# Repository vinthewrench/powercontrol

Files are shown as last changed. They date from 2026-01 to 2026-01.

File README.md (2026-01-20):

This repository contains a hardware power controller that enforces safe, predictable power-on and power-off behavior for a Raspberry Pi used in real-world automation systems.

It grew out of the work described in [Raspberry Pi Internet of Things – Part 029](https://www.vinthewrench.com/p/raspberry-pi-internet-of-things-part-029), where the problem wasn’t software, but power: a Pi running irrigation, valves, radios, or sensors cannot simply lose power without consequences. Filesystems corrupt, tasks stop mid-cycle, and batteries get drained dry.

The design documented here takes those ideas further by moving power control out of the Pi and into a small, dedicated controller. The Pi decides when it is safe to shut down; the hardware enforces when power is actually applied or removed. A latching relay does the physical switching, while simple signals coordinate startup, shutdown, and recovery when utility power fails or returns.

The result is a Raspberry Pi that behaves like part of a system, not a hobby board dangling from a power supply.
 
## Repository Layout

```
.
├── Power_Controller_Design_Document_v1.1.md
├── README.md
├── code/
│   └── powercontrol/
│       ├── powercontrol.c
│       ├── makefile
│       └── Doxyfile
└── hw/
    └── powercontrol_2.1/
        ├── powercontrol_2.1.kicad_sch
        ├── powercontrol_2.1.kicad_pcb
        ├── powercontrol_2.1.kicad_pro
        ├── powercontrol_2.1.kicad_prl
        └── build.zip
```

---

## Documentation

### Power_Controller_Design_Document_v1.1.md

This is the **authoritative design specification** for this project.

It defines:
- Hardware intent
- Firmware behavior
- I2C command contract
- Extended readback interface (`0xF0`)
- Design philosophy and explicit non-goals

## Firmware (`code/powercontrol`)

### Overview

The firmware runs on an AVR (ATmega8 / ATmega88 class) and provides:

- Latching relay control (pulse-only, never held)
- Manual wake via INT0
- AC_OK wake via INT1
- Red / Green status LEDs
- I2C slave interface (address `0x08`)
- Watchdog-style host supervision
- Low-power IDLE sleep when inactive

The firmware is **single-loop, flag-driven**, and avoids performing real work in ISRs.

### Files

- `powercontrol.c`  
  Main firmware implementation. This is the source of truth.

- `makefile`  
  Minimal AVR-GCC build file. No build system gymnastics.

- `Doxyfile`  
  Optional Doxygen configuration for generating internal documentation.

### Build

Typical workflow:

```
cd code/powercontrol
make
make flash
```

Target MCU, programmer, and fuses are defined in the makefile and are expected to be adjusted per environment.

## Hardware (`hw/powercontrol_2.1`)

This directory contains the **KiCad revision 2.1** of the Power Controller board.

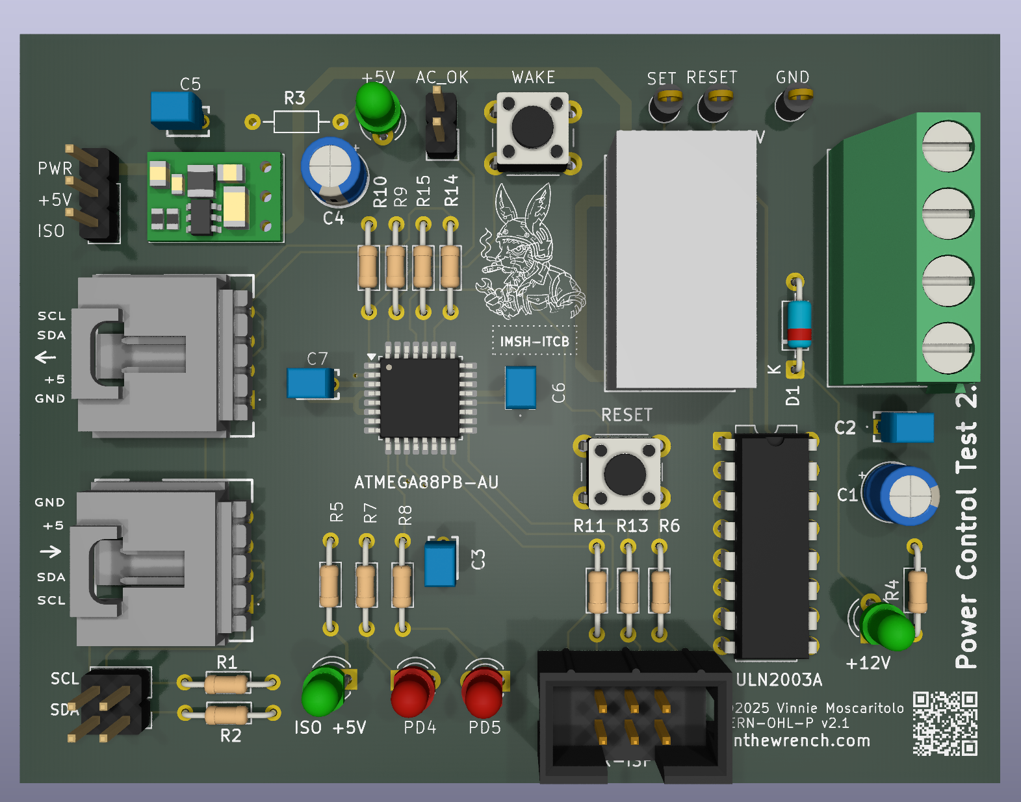
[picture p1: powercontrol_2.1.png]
Power Controller v2.1


### Hardware Summary

- +12 V input
- On-board 5 V regulator
- AVR MCU running internal 8 MHz RC oscillator
- ULN2003A relay driver
- Dual-coil latching relay
- Manual wake button
- AC_OK external wake input
- I2C interface with series protection resistors
- Explicit power and ground wiring (no hidden pins)

The MCU remains powered at all times so it can observe wake events even when the downstream system is off.

### Fabrication

`build.zip` contains fabrication outputs (Gerbers, drill files, etc.) suitable for board manufacturing.

## I2C Interface (Summary)

- **Address**: `0x08`
- **Write-only commands** for relay and LED control
- **Extended readback** via command `0xF0`

Example:

```
i2ctransfer -y 1 w1@0x08 0xF0 r4
```

Expected response:

```
0x13 status_byte timer_MSB timer_LSB
```

###  I2C Command Set

| Command | Function |
|---|---|
| 0x00 | NO-OP watchdog ping |
| 0x01 | Relay OFF |
| 0x02 | Relay ON |
| 0x03 | Red LED OFF |
| 0x04 | Red LED ON |
| 0x05 | Green LED OFF |
| 0x06 | Green LED ON |
| 0x10 | Set ping timeout (uint16 ms) |

---

## Non-Goals

This project explicitly does **not** attempt to provide:

- RTC or scheduling
- Network connectivity
- Filesystems
- Soft power control
- UPS functionality

Those responsibilities belong on the host system.

## Design Intent (Plain English)

If the host behaves, it stays powered.  
If it locks up, it gets cut off and restarted.  
If a human presses the button, power comes on.  
If AC disappears, the system reacts predictably.

## License

- **Firmware / Software**: MIT License  
- **Hardware designs**: CERN-OHL-P v2 (Permissive Open Hardware Licence)

Copyright © 2026 Vinnie Moscaritolo

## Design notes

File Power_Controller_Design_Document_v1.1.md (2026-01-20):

# Power Controller Design Document

## 1. Purpose

The Power Controller is a small, deterministic embedded controller whose sole job is to reliably apply and remove power to a downstream system (typically a Raspberry Pi or similar SBC), while providing:

- Hard power cut and restore via a latching relay
- Manual wake capability
- External wake from an AC-present signal
- Simple visual status via red/green LEDs
- A minimal I2C command interface
- Predictable low-power idle behavior

This board is intentionally boring. No cloud, no OS assumptions, no timing magic. It exists to do one thing well: decide when power flows.

---

## 2. Design Philosophy

- Deterministic: All behavior is explicit and bounded.
- Offline-first: No network dependency.
- Fail-safe bias: Loss of MCU control defaults to relay OFF.
- Serviceable: ISP header, visible LEDs, simple signals.
- Conservative silicon: AVR, ULN2003, latching relay.

---

## 3. Functional Overview

The controller runs continuously from +12 V and selectively switches a separate +12 V switched output feeding the downstream system.

---

## 4. Hardware Architecture

### 4.1 Microcontroller

- ATmega8 / ATmega88 class AVR
- Internal 8 MHz RC oscillator
- No external crystal

### 4.2 Power Regulation

- +12 V input
- Pololu D45V5F5 buck regulator
- +5 V MCU rail

### 4.3 Relay Driver

- Dual-coil latching relay
- ULN2003A driver
- Pulse-only coil drive

### 4.4 LEDs

- Red: fault/timeout
- Green: power ON
- Active-low GPIO drive

### 4.5 Wake Inputs

- INT0: manual wake button
- INT1: AC_OK relay contact

### 4.6 I2C Interface

- Slave address: 0x08
- Watchdog, relay, LED control

---

## 5. Firmware Architecture

- Single main loop
- ISRs set flags only
- IDLE sleep when inactive

### 5.0 Extended I2C Readback

The controller supports an extended read transaction for diagnostics and host verification.

**Command**: `0xF0`  
**Read length**: 4 bytes

**Response format**:

| Byte | Description |
|---|---|
| 0 | Firmware version (`0x13`) |
| 1 | Status byte |
| 2 | Timer MSB |
| 3 | Timer LSB |

**Linux example**:

```
i2ctransfer -y 1 w1@0x08 0xF0 r4
```

**Expected response example**:

```
0x13 0x00 0x00 0x00
```

This indicates firmware version 0x13, status = 0, and timer = 0 ms.

This read path is side-effect free and may be called at any time.

---

### 5.1 I2C Command Set

| Command | Function |
|---|---|
| 0x00 | NO-OP watchdog ping |
| 0x01 | Relay OFF |
| 0x02 | Relay ON |
| 0x03 | Red LED OFF |
| 0x04 | Red LED ON |
| 0x05 | Green LED OFF |
| 0x06 | Green LED ON |
| 0x10 | Set ping timeout (uint16 ms) |

---

## 6. Safety and Robustness

- Series resistors on ISP and I2C
- No +12 V exposure to MCU pins
- Latching relay prevents thrash

---

## 7. Use Cases

- SBC power watchdog
- Unattended systems
- Farm and off-grid electronics

---

## 8. Non-Goals

- No RTC
- No scheduler
- No network stack

---

## 9. Summary

Power should be deliberate, observable, and recoverable.

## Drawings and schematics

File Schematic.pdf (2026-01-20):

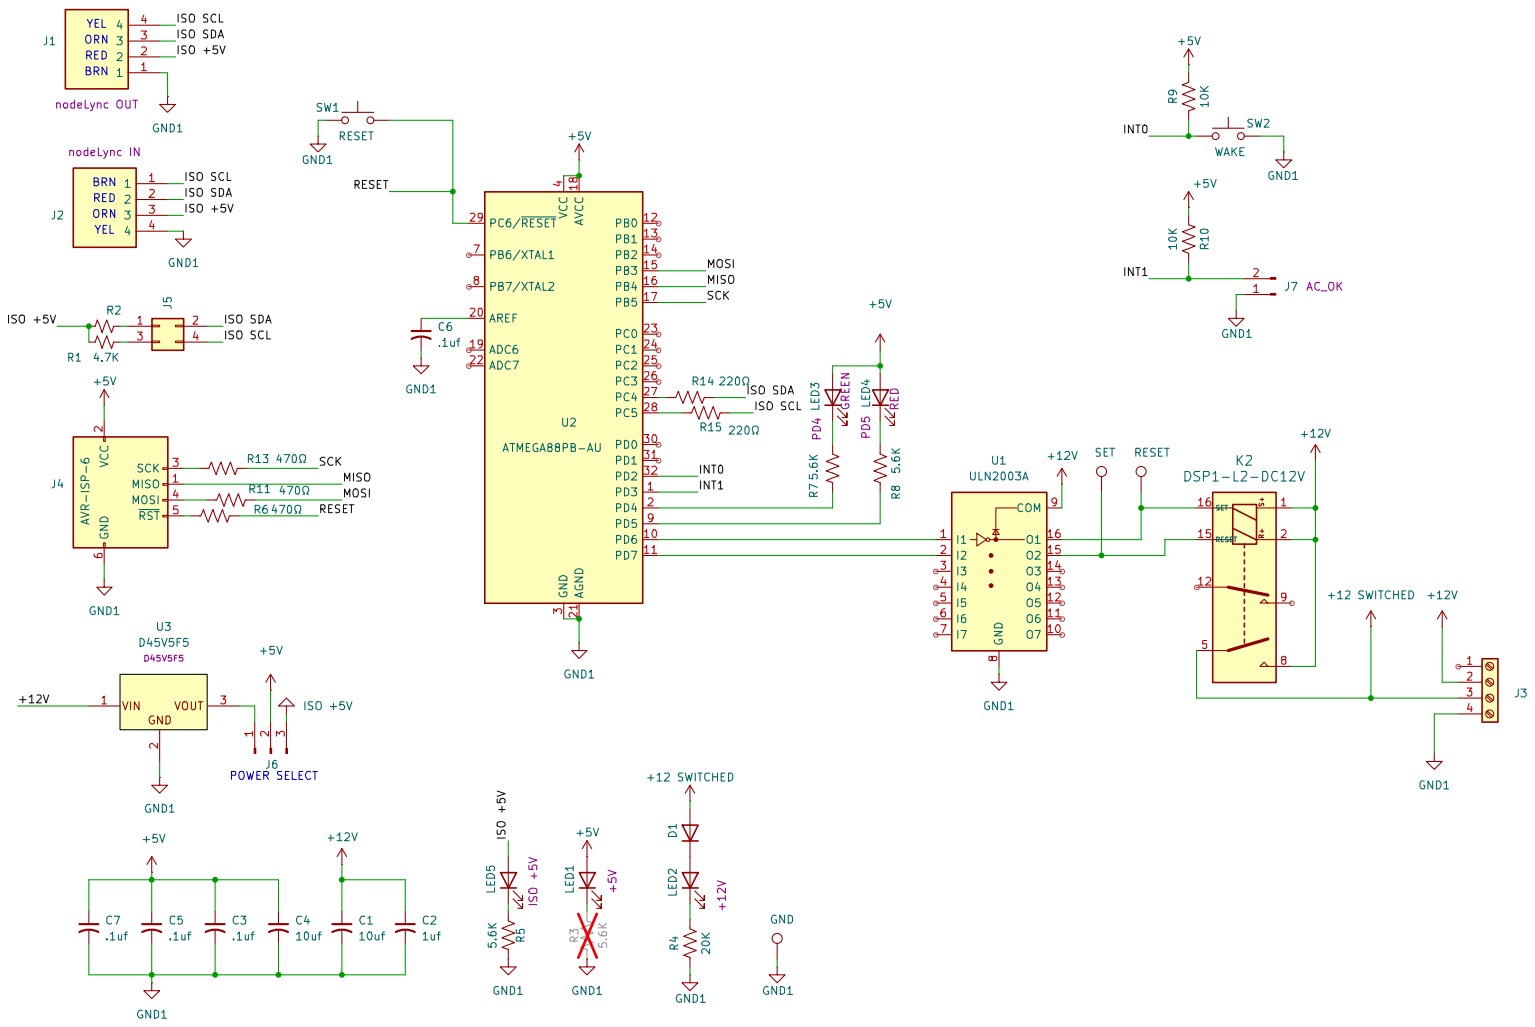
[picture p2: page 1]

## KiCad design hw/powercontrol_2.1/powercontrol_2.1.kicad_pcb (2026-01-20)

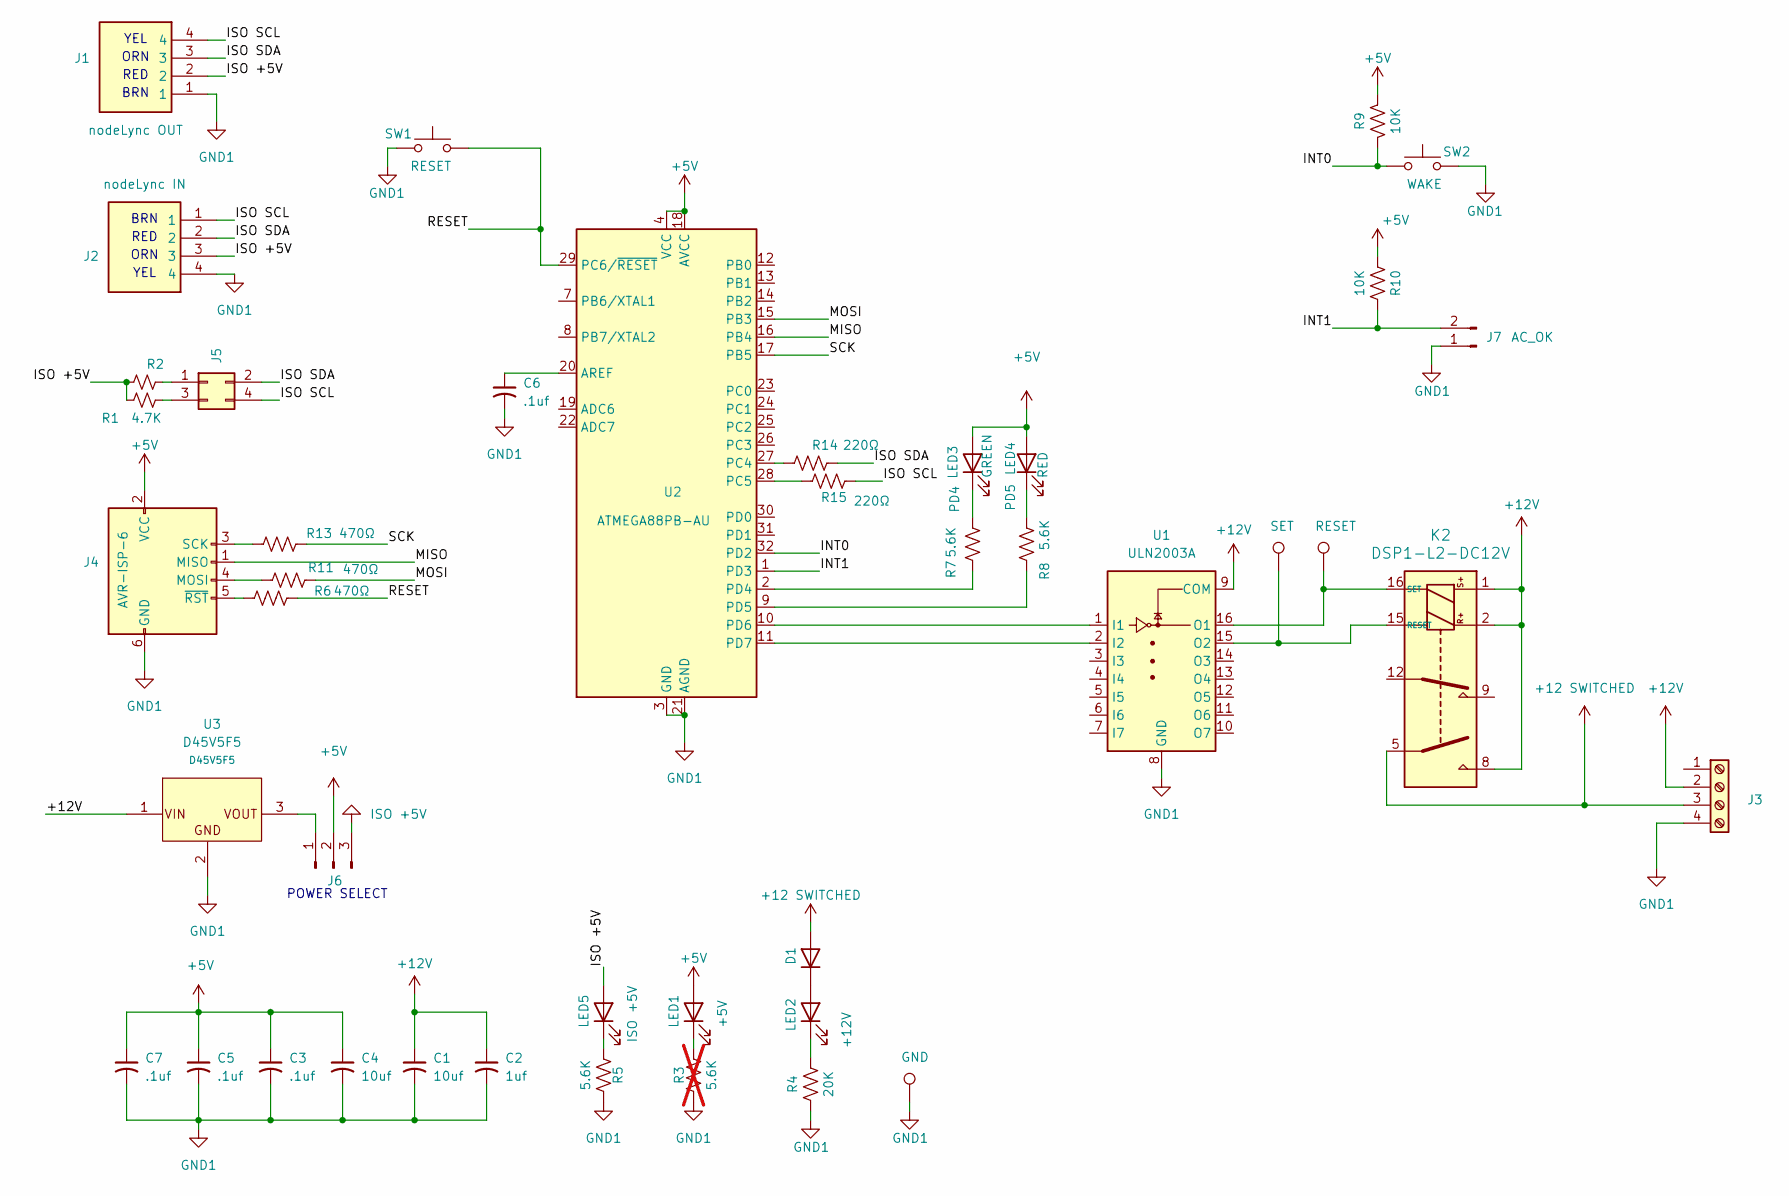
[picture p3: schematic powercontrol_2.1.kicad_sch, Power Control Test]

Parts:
C1, C4: 10uf; CP_Radial_D5.0mm_P2.00mm
C2: 1uf; RCER71H104K0DBH03A
C3, C5, C6, C7: .1uf; RCER71H104K0DBH03A
D1: 1N4148WS; D_DO-35_SOD27_P7.62mm_Horizontal
J1, J2: 70551-0003; 705510003; Manufacturer_Part_Number 70551-0003; Mouser Part Number 538-70551-0003
J3: +12; TerminalBlock_Phoenix_MKDS-1,5-4-5.08_1x04_P5.08mm_Horizont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
J4: AVR-ISP-6; PinHeader_2x03_P2.54mm_Vertical
J5: Conn_02x02_Odd_Even; PinHeader_2x02_P2.54mm_Vertical
J6: Conn_01x03_Pin; PinHeader_1x03_P2.54mm_Vertical
J7: Conn_01x02_Pin; PinHeader_1x02_P2.54mm_Vertical
K2: DSP1-L2-DC12V
LED1, LED2, LED3, LED5: 151033GS03000; LED_D3.0mm
LED4: 151033RS03000; LED_D3.0mm
R1, R2: 4.7K; R_Axial_DIN0204_L3.6mm_D1.6mm_P7.62mm_Horizontal
R3: 5.6K; R_Axial_DIN0204_L3.6mm_D1.6mm_P7.62mm_Horizontal; not fitted
R4: 20K; R_Axial_DIN0204_L3.6mm_D1.6mm_P7.62mm_Horizontal
R5, R7, R8: 5.6K; R_Axial_DIN0204_L3.6mm_D1.6mm_P7.62mm_Horizontal
R6, R11, R13: 470Ω; R_Axial_DIN0204_L3.6mm_D1.6mm_P7.62mm_Horizontal
R9, R10: 10K; R_Axial_DIN0204_L3.6mm_D1.6mm_P7.62mm_Horizontal
R14, R15: 220Ω; R_Axial_DIN0204_L3.6mm_D1.6mm_P7.62mm_Horizontal
SW1: RESET; SW_PUSH_6mm
SW2: WAKE; SW_PUSH_6mm
TP1: SET; 5000
TP2: RESET; 5000
TP3: GND; 5000
U1: ULN2003A; DIP-16_W7.62mm
U2: ATMEGA88PB-AU; TQFP-32_7x7mm_P0.8mm
U3: D45V5F5

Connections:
+5V: C3.1, C4.1, C5.1, C7.1, J4.2 (VCC), J6.2, LED1.2 (A), LED3.2 (A), LED4.2 (A), R9.2, R10.2, U2.4 (VCC), U2.6 (VCC), U2.18 (AVCC)
+12 SWITCHED: D1.2 (A), J3.3, K2.5
+12V: C1.1, C2.1, J3.2, K2.1, K2.2, K2.8, U1.9 (COM), U3.1 (VIN)
/INT0: R9.1, SW2.2, U2.32 (PD2)
/INT1: J7.2, R10.1, U2.1 (PD3)
/ISO SCL: J1.4, J2.1, J5.4, R15.1
/ISO SDA: J1.3, J2.2, J5.2, R14.1
/MISO: J4.1 (MISO), U2.16 (PB4)
/MOSI: R11.1, U2.15 (PB3)
/RESET: R6.1, SW1.2, U2.29 (PC6/~RESET)
/SCK: R13.1, U2.17 (PB5)
GND1: C1.2, C2.2, C3.2, C4.2, C5.2, C6.2, C7.2, J1.1, J2.4, J3.4, J4.6 (GND), J7.1, R3.1, R4.2, R5.2, SW1.1, SW2.1, TP3.1, U1.8 (GND), U2.3 (GND), U2.5 (GND), U2.21 (AGND), U3.2 (GND)
ISO +5V: J1.2, J2.3, J6.3, LED5.2 (A), R1.2, R2.2
unnamed: D1.1 (K), LED2.2 (A)
unnamed: J4.4 (MOSI), R11.2
unnamed: J4.3 (SCK), R13.2
unnamed: J4.5 (~RST), R6.2
unnamed: J5.1, R2.1
unnamed: J5.3, R1.1
unnamed: J6.1, U3.3 (VOUT)
unnamed: K2.15 (RESET), TP1.1, U1.15 (O2)
unnamed: K2.16 (SET), TP2.1, U1.16 (O1)
unnamed: LED1.1 (K), R3.2
unnamed: LED2.1 (K), R4.1
unnamed: LED3.1 (K), R7.2
unnamed: LED4.1 (K), R8.2
unnamed: LED5.1 (K), R5.1
unnamed: U1.1 (I1), U2.10 (PD6)
unnamed: U1.2 (I2), U2.11 (PD7)
unnamed: C6.1, U2.20 (AREF)
unnamed: R14.2, U2.27 (PC4)
unnamed: R15.2, U2.28 (PC5)
unnamed: R7.1, U2.2 (PD4)
unnamed: R8.1, U2.9 (PD5)

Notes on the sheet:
ORN
BRN
YEL
RED
POWER SELECT

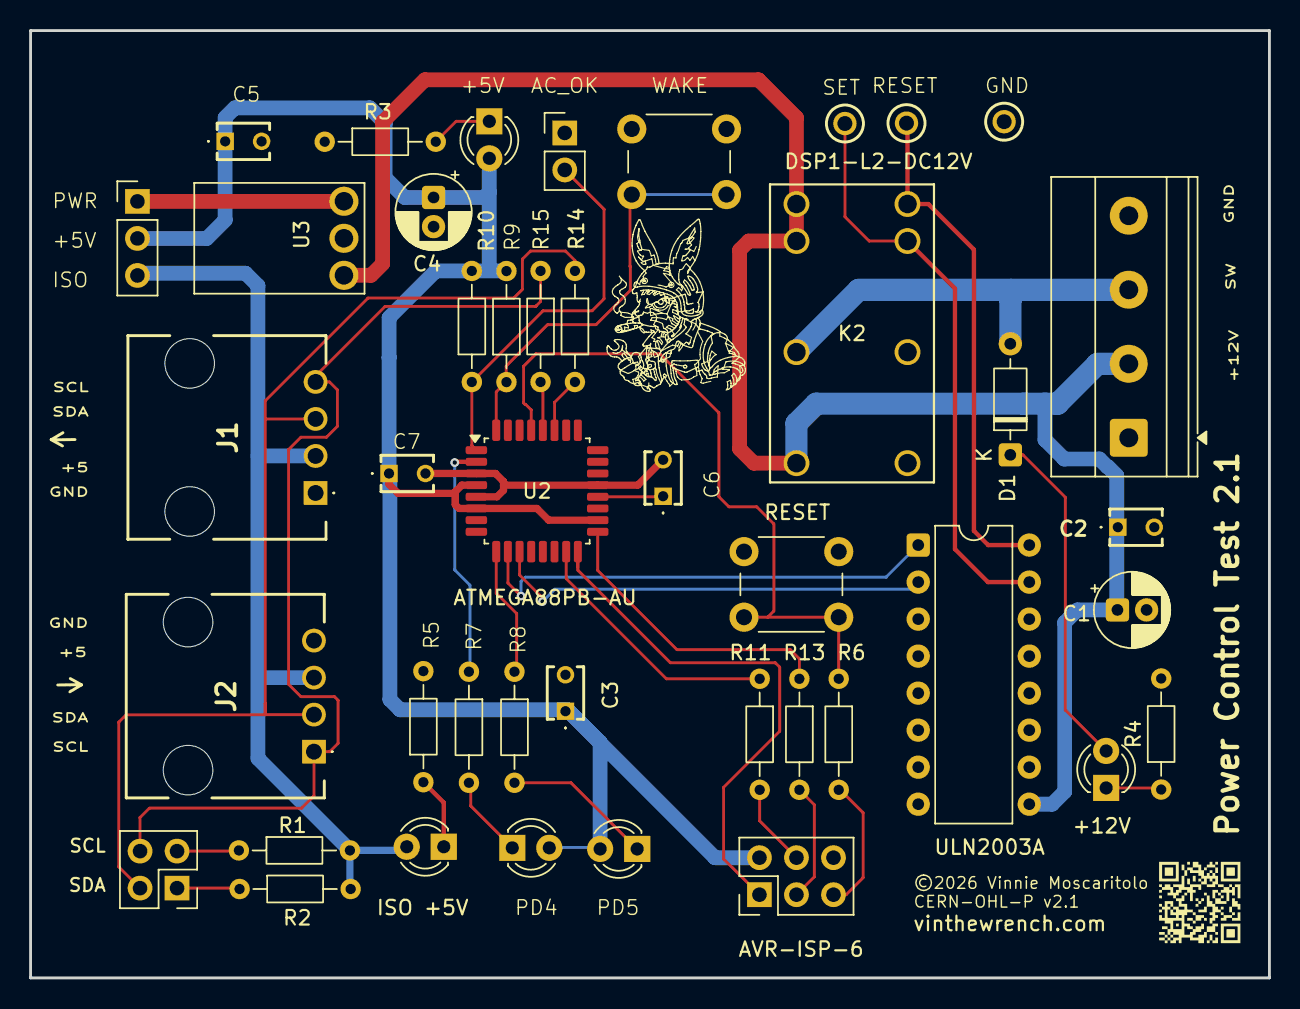
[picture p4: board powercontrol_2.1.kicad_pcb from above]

Board: 2 copper layers, 85.0 x 65.0 mm, 43 parts (0 on the bottom side), 34 nets.

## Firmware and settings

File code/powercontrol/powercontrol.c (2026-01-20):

/**
 * @file powercontrol.c
 * @brief Power Controller Firmware for ATmega88PB – Manages relay, LEDs, sleep, and I2C commands.
 *
 * This firmware controls a latching power relay, red/green LEDs, and implements low-power sleep/wake
 * behavior. It operates as an I2C slave at address 0x08, accepting commands to control the relay
 * and LEDs, and supports a programmable wake-up timer stored in EEPROM.
 *
 * @note Key features:
 * - Deferred relay pulses (set in main loop, never in ISR)
 * - Independent control of active-low red (PD5) and green (PD4) LEDs
 * - Power-down sleep mode with wakeup via:
 *   - User button (INT0, active-low, PD2)
 *   - AC_OK signal rising edge (INT1, PD3)
 *   - Watchdog-based wake timer (minutes)
 * - Software-based rising-edge detection for AC_OK
 * - Persistent wake timer configuration via EEPROM
 * - Hardware watchdog enabled for system reliability
 *
 * @note Assumptions:
 * - Internal 8 MHz RC oscillator (no external crystal)
 * - LEDs are active-low (ON = pin low)
 * - Button is pulled to GND on PD2 with internal pull-up
 * - AC_OK is HIGH when power supply is active (rising edge triggers wakeup)
 * - Relay is dual-coil latching type (set/reset coils pulsed briefly)
 *
 * @note Limitations:
 * - Multi-byte I2C writes supported only for wake timer (command 0x07 + 2 bytes)
 * - Read operations return single status byte or extended status (register pointer)
 * - No I2C error recovery beyond basic reset
 * - Timer accuracy approximate (~1 min resolution, subject to RC oscillator drift)
 *
 * @note Build & Flash:
 * - Compile: `avr-gcc -mmcu=atmega88pb -Os -o powercontrol.elf powercontrol.c`
 * - Flash: `avrdude -c usbasp -p m8 -U flash:w:powercontrol.elf`
 * - Recommended fuses (internal 8 MHz, BOD 2.7V): `-U lfuse:w:0xE4:m -U hfuse:w:0xD9:m`
 *
 * @note Stack usage: ~150 bytes maximum (estimated; flat structure, shallow ISRs)
 */
/* test
 *
 * # Detect device
 sudo i2cdetect -y 1

 * # Status byte only
 i2cget -y 1 0x08

 * # Extended read example (FW version, status byte, timer MSB, timer LSB)
 * # Expect: 0x13 status_byte timer_MSB timer_LSB (e.g., 0x13 0x00 0x00 0x00 if timer=0 and status=0)
 i2ctransfer -y 1 w1@0x08 0xF0 r4

 # LED tests
 i2cset -y 1 0x08 0x04 # RED ON
 i2cset -y 1 0x08 0x06 # GREEN ON (RED stays ON)
 i2cset -y 1 0x08 0x05 # GREEN OFF (RED stays ON)
 i2cset -y 1 0x08 0x03 # RED OFF
# Relay tests
 i2cset -y 1 0x08 0x01 # Relay OFF
 i2cset -y 1 0x08 0x02 # Relay ON

 * # Timer test (set 1 minute wake-up)
 i2ctransfer -y 1 w3@0x08 0x07 0x00 0x01 # MSB LSB for 1 min

 */
#include <avr/io.h>         // AVR I/O definitions (ports, bits, etc.)
#include <avr/interrupt.h>  // Interrupt handling
#include <util/delay.h>     // Delay functions (_delay_ms)
#include <util/twi.h>       // Two-Wire Interface (I2C) utilities
#include <avr/wdt.h>        // Watchdog timer
#include <avr/eeprom.h>     // EEPROM read/write
#include <avr/sleep.h>      // Sleep modes
#include <stdbool.h>        // Boolean type
#include <stdint.h>         // Standard integer types (uint8_t, etc.)
#include <stddef.h>         // offsetof for struct checksum

/* =========================================================
 * MCU REGISTER COMPATIBILITY (atmega88pb vs ATmega88/88PB)
 * =========================================================
 *
 * ATmega8 uses:
 *   MCUCR, GICR, GIFR, TIMSK, TIFR
 *
 * ATmega88/88PB uses:
 *   EICRA, EIMSK, EIFR, TIMSK1, TIFR1
 *
 * Bit names (ISC01, ISC00, ISC11, ISC10, INT0, INT1, INTF0, INTF1, OCIE1A, OCF1A)
 * are consistent, but the registers holding them differ.
 */
#if defined(__AVR_ATmega8__)
#define EXTINT_CTRL_REG MCUCR
#define EXTINT_MASK_REG GICR
#define EXTINT_FLAG_REG GIFR
#define TIMER1_TIMSK_REG TIMSK
#define TIMER1_TIFR_REG TIFR
#else
#define EXTINT_CTRL_REG EICRA
#define EXTINT_MASK_REG EIMSK
#define EXTINT_FLAG_REG EIFR
#define TIMER1_TIMSK_REG TIMSK1
#define TIMER1_TIFR_REG TIFR1
#endif

/**
 * @brief Forward declarations for functions.
 */
static void i2c_init(void);
static void extint_config_run_edges(void);
static void timer1_init_1s(void);
static inline void timer1_stop(void);

/* ---------------------------------------------------------
 * Clock Configuration
 * --------------------------------------------------------- */
/** @brief CPU frequency (internal RC oscillator). */
#ifndef F_CPU
#define F_CPU 8000000UL
#endif

/** @brief Adjusted Timer1 compare value for closer ~1s ticks (8MHz / 1024 prescaler). */
#define TIMER1_OCR1A 6695

/** @brief Calibrated OSCCAL value for internal oscillator (tune based on measurement; example mid-range). */
#define CALIBRATED_OSCCAL 0x80

/* =========================================================
 * I2C SLAVE ADDRESS
 * ========================================================= */
/** @brief 7-bit I2C slave address for this device. */
#define I2C_ADDR 0x08

/* =========================================================
 * GPIO ASSIGNMENTS (LOCKED)
 * ========================================================= */
/** @brief Green LED pin on PORTD. Active-low (ON when low). */
#define GREEN_LED PD4
/** @brief Red LED pin on PORTD. Active-low (ON when low). */
#define RED_LED PD5
/** @brief Relay set coil pin on PORTD. Pulse to turn relay ON. */
#define RELAY_SET PD6
/** @brief Relay reset coil pin on PORTD. Pulse to turn relay OFF. */
#define RELAY_RESET PD7
/** @brief AC_OK input pin (INT1) on PORTD. High when PSU on. */
#define INT1_PIN PD3 /* AC_OK (INT1) */
/** @brief User button input pin (INT0) on PORTD. Active-low. */
#define INT0_PIN PD2 /* user button (INT0) */

/* =========================================================
 * HARDWARE WATCHDOG
 * ========================================================= */
/** @brief Watchdog timeout period (2 seconds). */
#define HW_WDT_TIMEOUT WDTO_2S

/** @brief Command for extended status read (register start). */
#define CMD_READ_EXT_STATUS 0xF0
/** @brief Firmware version byte (0x13). */
#define FW_VERSION 0x20 /* current version */

/** @brief Command for setting wake-up timer (multi-byte). */
#define CMD_SET_WAKE_TIMER 0x07

/** @brief Max wake timer minutes (1 day) to prevent indefinite sleep. */
#define MAX_WAKE_TIMER_MIN 1440

/* =========================================================
 * EEPROM CONFIG (kept for future use)
 * ========================================================= */
/** @brief EEPROM signature ('P''C'). */
#define EEPROM_SIGNATURE 0x5043 /* 'P''C' */
/** @brief EEPROM config version. */
#define EEPROM_VERSION 0x01

/**
 * @brief EEPROM configuration structure.
 */
typedef struct {
    uint16_t signature; /**< Signature for validity check. */
    uint8_t version; /**< Config version. */
    uint16_t wake_timer_min; /**< Wake-up timer in minutes (persisted). */
    uint16_t checksum; /**< Fletcher-16 checksum over prior bytes. */
} eeprom_cfg_t;

/** @brief EEPROM base address. */
#define EEPROM_BASE_ADDR 0x00

/**
 * @brief Persistent configuration loaded from EEPROM.
 *
 * This structure holds user-configured policy values that are:
 * - Loaded once from EEPROM at boot
 * - Updated explicitly by main-line code (e.g. via I2C commands)
 * - Cached in RAM for all runtime decisions
 *
 * Important:
 * - It is never modified inside an ISR
 * - It does not represent hardware or asynchronous state
 * - Allowing the compiler to optimize access is correct
 *
 * EEPROM is only accessed when explicitly loading or saving this
 * structure; all runtime logic uses this cached copy.
 */
static eeprom_cfg_t cfg;

/**
 * @brief Compute Fletcher-16 checksum.
 * @param data Pointer to data buffer.
 * @param len Length of data.
 * @return Checksum value.
 */
uint16_t config_fletcher16(const void *data, size_t len)
{
    const uint8_t *p = (const uint8_t *)data;
    uint16_t sum1 = 0;
    uint16_t sum2 = 0;
    while (len--) {
        sum1 = (sum1 + *p++) % 255;
        sum2 = (sum2 + sum1) % 255;
    }
    return (sum2 << 8) | sum1;
}

/**
 * @brief Compute checksum for config struct (up to but not including checksum field).
 * @param cfg Pointer to config struct.
 * @return Checksum.
 */
static uint16_t cfg_checksum(const eeprom_cfg_t *cfg)
{
    return config_fletcher16(cfg, offsetof(eeprom_cfg_t, checksum));
}

/**
 * @brief Load persistent configuration from EEPROM into global cfg.
 *
 * Reads the EEPROM block into the global cfg structure and validates it.
 *
 * Validation checks:
 * - Signature matches EEPROM_SIGNATURE
 * - Version matches EEPROM_VERSION
 * - Checksum is correct
 *
 * @return 1 if EEPROM contents are valid and cfg is populated,
 *         0 if EEPROM contents are invalid.
 */
static uint8_t eeprom_load_cfg(void)
{
    /* Read entire config block from EEPROM into global cfg */
    eeprom_read_block((void *)&cfg,
                      (const void *)EEPROM_BASE_ADDR,
                      sizeof(cfg));
    /* Validate signature */
    if (cfg.signature != EEPROM_SIGNATURE)
        return 0;
    /* Validate version */
    if (cfg.version != EEPROM_VERSION)
        return 0;
    /* Validate checksum */
    if (cfg.checksum != cfg_checksum(&cfg))
        return 0;
    return 1;
}

/**
 * @brief Initialize global cfg with default values.
 *
 * This is used when EEPROM contents are invalid or uninitialized.
 * The defaults establish a known-good policy state.
 */
static void eeprom_default_cfg(void)
{
    cfg.signature = EEPROM_SIGNATURE;
    cfg.version = EEPROM_VERSION;
    cfg.wake_timer_min = 1; /**< Default: 1 minute wake timer configured */
    /* Compute checksum over initialized fields */
    cfg.checksum = cfg_checksum(&cfg);
}

/**
 * @brief Save global cfg to EEPROM.
 *
 * Updates the checksum and writes the entire configuration block
 * to EEPROM using update semantics to minimize wear.
 *
 * EEPROM is written only when policy changes.
 */
static void eeprom_save_cfg(void)
{
    /* Update checksum before persisting */
    cfg.checksum = cfg_checksum(&cfg);
    /* Write global cfg to EEPROM */
    eeprom_update_block((const void *)&cfg,
                        (void *)EEPROM_BASE_ADDR,
                        sizeof(cfg));
}

/* =========================================================
 * SOFTWARE STATE
 * ========================================================= */
/** @brief I2C register pointer for multi-byte reads. */
static volatile uint8_t i2c_reg_ptr = 0;
/** @brief I2C rx state for multi-byte writes (0 idle, 1 expect MSB, 2 expect LSB). */
static volatile uint8_t rx_state = 0;
/** @brief Temporary buffer for multi-byte I2C data (e.g., timer). */
static volatile uint16_t rx_tmp = 0;
/** @brief Deferred wake timer value (minutes) from I2C. */
static volatile uint16_t deferred_wake_timer = 0;
/** @brief Flag for pending timer update. */
static volatile bool timer_update_pending = false;
/** @brief Remaining wake-up timer in minutes (0 = disabled). */
static volatile uint16_t wake_timer_min = 0;
/** @brief Second counter for timer (decrements every 1s interrupt). */
static volatile uint8_t timer_seconds = 0;
/** @brief Flag for timer expiration wake. */
static volatile bool timer_expired = false;
/** @brief Current relay state (1 = ON). */
static volatile uint8_t relay_state = 0;
/** @brief Current red LED state (1 = ON). */
static volatile uint8_t red_state = 0;
/** @brief Current green LED state (1 = ON). */
static volatile uint8_t green_state = 0;
/** @brief Flag for button press wake event (one-shot). */
static volatile uint8_t wake_flag = 0;
/** @brief Latch for Pi-requested shutdown (1 = requested). */
static volatile uint8_t pi_shutdown_requested = 0;
/** @brief Flag for active shutdown sleep cycle (prevents timer reload on partial wakes). */
static volatile bool shutdown_sleep_active = false;
/** @brief Previous AC_OK state for edge detection. */
static uint8_t ac_ok_prev = 0;

/**
 * @brief Enum for deferred relay requests (to avoid pulses in ISR).
 */
typedef enum {
    RELAY_REQ_NONE = 0, /**< No request pending. */
    RELAY_REQ_ON, /**< Request to turn relay ON. */
    RELAY_REQ_OFF /**< Request to turn relay OFF. */
} relay_req_t;

/** @brief Pending relay request. */
static volatile relay_req_t relay_req = RELAY_REQ_NONE;

/* =========================================================
 * LED HELPERS
 * ========================================================= */
/**
 * @brief Turn red LED on/off.
 * @param on True to turn on (active-low), false to off.
 */
static inline void led_red(bool on)
{
    if (on) { PORTD &= ~(1 << RED_LED); red_state = 1; } // Set pin low for ON
    else { PORTD |= (1 << RED_LED); red_state = 0; } // Set pin high for OFF
}

/**
 * @brief Turn green LED on/off.
 * @param on True to turn on (active-low), false to off.
 */
static inline void led_green(bool on)
{
    if (on) { PORTD &= ~(1 << GREEN_LED); green_state = 1; } // Set pin low for ON
    else { PORTD |= (1 << GREEN_LED); green_state = 0; } // Set pin high for OFF
}

/**
 * @brief Blink an LED in main loop (busy-wait, disables TWI temporarily).
 * @param pin Pin to blink (RED_LED or GREEN_LED).
 * @param count Number of blinks.
 */
static void led_blink(uint8_t pin, uint8_t count)
{
    uint8_t twcr_saved = TWCR; // Save TWI control register
    TWCR &= ~(1 << TWIE); // Disable TWI interrupts to avoid conflicts during blink
    uint8_t red_was = red_state; // Save current states
    uint8_t green_was = green_state;
    for (uint8_t i = 0; i < count; i++) {
        if (pin == RED_LED) led_red(true); // Turn on
        else led_green(true);
        for (uint8_t k = 0; k < 25; k++) { // ~250ms delay (shortened for faster boot)
            _delay_ms(10);
            wdt_reset(); // Reset watchdog during long delays
        }
        if (pin == RED_LED) led_red(false); // Turn off
        else led_green(false);
        for (uint8_t k = 0; k < 25; k++) { // ~250ms delay
            _delay_ms(10);
            wdt_reset();
        }
    }
    TWCR = twcr_saved; // Restore TWI
    led_red(red_was); // Restore original states
    led_green(green_was);
}

/* =========================================================
 * RELAY HELPERS (main only)
 * ========================================================= */
/** @brief Relay coil pulse duration in ms. */
#define RELAY_PULSE_MS 30

/**
 * @brief Pulse a relay coil pin.
 * @param pin Pin to pulse (RELAY_SET or RELAY_RESET).
 */
static inline void relay_pulse(uint8_t pin)
{
    PORTD &= ~((1 << RELAY_SET) | (1 << RELAY_RESET)); // Ensure both coils off
    PORTD |= (1 << pin); // Pulse selected pin
    _delay_ms(RELAY_PULSE_MS); // Pulse duration ~30ms; may vary slightly with clock drift
    PORTD &= ~(1 << pin); // Release
}

/**
 * @brief Apply relay state change.
 * @param on True for ON (set pulse), false for OFF (reset pulse).
 */
static inline void relay_apply(bool on)
{
    if (on) {
        relay_pulse(RELAY_SET); // Pulse set coil
        relay_state = 1; // Update state
    } else {
        relay_pulse(RELAY_RESET);// Pulse reset coil
        relay_state = 0; // Update state
    }
}

/* ===========================
 * POWER_DOWN ADDITIONS
 * =========================== */
#define WDT_TICKS_PER_MIN 30 /* 2s WDT × 30 ≈ 60s */
static volatile uint8_t wdt_ticks = 0;

/* ---------------------------
 * Watchdog interrupt only
 * --------------------------- */
ISR(WDT_vect)
{
    wdt_ticks++;
    if (wdt_ticks >= WDT_TICKS_PER_MIN) {
        wdt_ticks = 0;
        if (wake_timer_min > 0) {
            wake_timer_min--;
            if (wake_timer_min == 0) {
                timer_expired = true;
            }
        }
    }
}

/* ---------------------------
 * Arm watchdog for sleep
 * --------------------------- */
static inline void wdt_arm_interrupt(void)
{
    cli();
    wdt_reset();
    WDTCSR = (1 << WDCE) | (1 << WDE);
    WDTCSR =
        (1 << WDIE) | /* interrupt only */
        (1 << WDP2) | (1 << WDP1) | (1 << WDP0); /* ~2s */
    sei();
}

/* ---------------------------
 * Stop watchdog
 * --------------------------- */
static inline void wdt_stop(void)
{
    cli();
    wdt_reset();
    WDTCSR = (1 << WDCE) | (1 << WDE);
    WDTCSR = 0;
    sei();
}

/* =========================================================
 * SLEEP SUPPORT (POWER_DOWN)
 * ========================================================= */
static void prepare_for_sleep_powerdown(void)
{
    /* HARD stop Timer1 before anything else */
    timer1_stop();
    /* Disable TWI */
    TWCR = 0;
    /* FIX: remove AC_OK pull-up during sleep */
    PORTD &= ~(1 << INT1_PIN);
    /* Disable ADC and analog comparator */
    ADCSRA &= ~(1 << ADEN);
    ACSR |= (1 << ACD);
    /* Shut down peripherals deterministically */
    PRR =
        (1 << PRADC) |
        (1 << PRTWI) |
        (1 << PRTIM0) |
        (1 << PRTIM1) |
        (1 << PRSPI) |
        (1 << PRUSART0);
    /* Clear and enable wake sources */
    EXTINT_FLAG_REG |= (1 << INTF0) | (1 << INTF1);
    EXTINT_MASK_REG |= (1 << INT0) | (1 << INT1);
    /* LEDs physically off */
    PORTD |= (1 << RED_LED) | (1 << GREEN_LED);
    /* Arm watchdog interrupt only */
    wdt_arm_interrupt();
}
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
int main(void)
{
    /* Disable watchdog during early init */
    wdt_disable();
    cli(); /* No interrupts during hardware init */
    /* OSCCAL is a fixed, calibrated value.
     * Must be set before any timing-sensitive init and never changed at runtime.
     */
    OSCCAL = CALIBRATED_OSCCAL;
    io_init(); /* GPIO, LEDs, relay pins, ext interrupts */
    /* Force relay ON on power-up/reset */
    boot_force_relay_on();
    i2c_init(); /* I2C slave setup */
    sei(); /* Interrupts enabled */
    /* ------------------------------------------------------
     * Load persistent configuration (policy)
     * ------------------------------------------------------ */
    if (eeprom_load_cfg()) {
        led_blink(GREEN_LED, 5); /* EEPROM valid */
    } else {
        eeprom_default_cfg(); /* EEPROM invalid or blank */
        eeprom_save_cfg();
        led_blink(RED_LED, 5);
    }
    /* Establish AC_OK baseline for edge detection */
    ac_ok_prev = (PIND & (1 << INT1_PIN)) ? 1 : 0;
    /* Enable watchdog after system is stable */
    wdt_enable(HW_WDT_TIMEOUT);
    /* ======================================================
     * Main loop
     * ====================================================== */
    for (;;) {
        wdt_reset();
        /* ----------------------------------------------
         * Apply deferred relay requests from I2C ISR
         * ---------------------------------------------- */
        {
            relay_req_t r = RELAY_REQ_NONE;
            uint8_t s = SREG;
            cli();
            r = relay_req;
            relay_req = RELAY_REQ_NONE;
            SREG = s;
            if (r == RELAY_REQ_ON) relay_apply(true);
            if (r == RELAY_REQ_OFF) relay_apply(false);
        }
        /* ----------------------------------------------
         * Handle deferred wake timer update from I2C
         * ---------------------------------------------- */
        if (timer_update_pending) {
            uint8_t s = SREG;
            cli();
            cfg.wake_timer_min = deferred_wake_timer; /* update policy */
            timer_update_pending = false;
            SREG = s;
            eeprom_save_cfg(); /* persist policy */
            /* DO NOT arm timer here, only arm immediately before sleep */
        }
        /* ----------------------------------------------
         * Sleep policy
         * ----------------------------------------------
         * Enter sleep only when:
         * - Pi has requested shutdown
         * - Relay is OFF
         * ---------------------------------------------- */
        if (pi_shutdown_requested && !relay_state) {
            wdt_stop();
            rearm_int0();
            if (!shutdown_sleep_active) {
                reload_wake_timer();
                wdt_ticks = 0;
                shutdown_sleep_active = true;
            }
            prepare_for_sleep_powerdown();
            enter_sleep_powerdown();
            bool full_wake = false;
            bool button_wake = (wake_flag != 0);
            if (button_wake) {
                wake_flag = 0;
                /* Post-wake debounce (safe here, not in ISR) */
                _delay_ms(10);
                if (!(PIND & (1 << INT0_PIN))) {
                    full_wake = true;
                }
            }
            if (timer_expired) {
                timer_expired = 0;
                full_wake = true;
            }
            /* Fix: pass both prev and now to debounce/edge detect */
            {
                uint8_t ac_ok_now = (PIND & (1 << INT1_PIN)) ? 1 : 0;
                if (debounce_ac_ok(ac_ok_prev, ac_ok_now)) {
                    full_wake = true;
                }
                ac_ok_prev = ac_ok_now;
            }
            if (full_wake) {
                wdt_stop();
                restore_after_sleep_powerdown();
                relay_apply(true);
                pi_shutdown_requested = 0;
                shutdown_sleep_active = false;
                wdt_enable(HW_WDT_TIMEOUT);
                if (button_wake) {
                    rearm_int0();
                }
            }
        }
        /* ----------------------------------------------
         * AC_OK rising-edge wake (software edge detect)
         * ---------------------------------------------- */
        {
            uint8_t ac_ok_now = (PIND & (1 << INT1_PIN)) ? 1 : 0;
            if (debounce_ac_ok(ac_ok_prev, ac_ok_now)) {
                if (pi_shutdown_requested) {
                    timer1_stop();
                    relay_apply(true);
                    pi_shutdown_requested = 0;
                    shutdown_sleep_active = false;
                }
            }
            ac_ok_prev = ac_ok_now;
        }
    }
}

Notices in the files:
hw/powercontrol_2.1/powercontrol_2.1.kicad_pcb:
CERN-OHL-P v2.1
